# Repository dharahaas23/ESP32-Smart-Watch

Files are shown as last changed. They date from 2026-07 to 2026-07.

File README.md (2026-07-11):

# ESP32 Smart Watch

A round, wrist-worn smart watch built around the ESP32-WROOM-32, with heart-rate sensing, a circular color display, USB-C charging, and a custom PCB antenna — designed as part of the #30DaysOfPCB progression from beginner to advanced boards.

 

## Overview

| | |
|---|---|
| **MCU** | ESP32-WROOM-32 |
| **Display** | GC9A01, round TFT (SPI) |
| **Heart-rate sensor** | MAX30102 (I2C) |
| **Charger / protection** | TP4056 + DW01A + FS8205A dual MOSFET |
| **Regulator** | AMS1117-3.3 |
| **USB / programming** | USB-C, CH340K USB-to-TTL bridge |
| **Board shape** | Circular, with a keep-out zone and PCB trace antenna for the ESP32 |
| **Layers** | 4-layer (F.Cu, In1.Cu, In2.Cu, B.Cu) |
| **Pads / Vias / Track segments** | 227 / 78 / 306 |
| **Nets** | 68 (fully routed — 0 unrouted) |

## Features

- **ESP32-WROOM-32** as the main controller, with dedicated `RESET`, `EN`, `BOOT`, and `Button` GPIOs
- **GC9A01 round display** driven over SPI, with separate SDA/SCL/RST/DC/CS lines
- **MAX30102** heart-rate/SpO2 sensor on I2C, footprint placed close to the skin-contact edge for optimal readings
- **USB-C** input for power and CH340K-based UART programming (TXD/RXD/DTR/RTS wired to EN/BOOT for auto-reset)
- **TP4056** single-cell Li-ion charge management with **DW01A + FS8205A** battery protection (over-charge/discharge/current)
- **On/off slide switch** and separate **BOOT** and **Function** push buttons
- **Custom PCB trace antenna** for the ESP32, isolated behind a defined keep-out zone
- Battery connector (BAT+ / BAT−) for a coin/pouch cell

## Design Notes

- Front copper is heavily used for power distribution and the ESP32 antenna keep-out; back copper carries the bulk of signal routing.
- The board silkscreen calls out `PLACE CLOSE TO THE SKIN` next to the MAX30102 footprint as a placement reminder for future revisions/enclosure design.
- Bottom silk includes maker/GitHub branding (`GitHub:dharahaas23`) and a "Designed with KiCad" mark.

## Tools

- **KiCad 10.0.1** — schematic capture, PCB layout, and 3D visualization

## Author

**S. Dharahaas**
GitHub: [@dharahaas23](https://github.com/dharahaas23)

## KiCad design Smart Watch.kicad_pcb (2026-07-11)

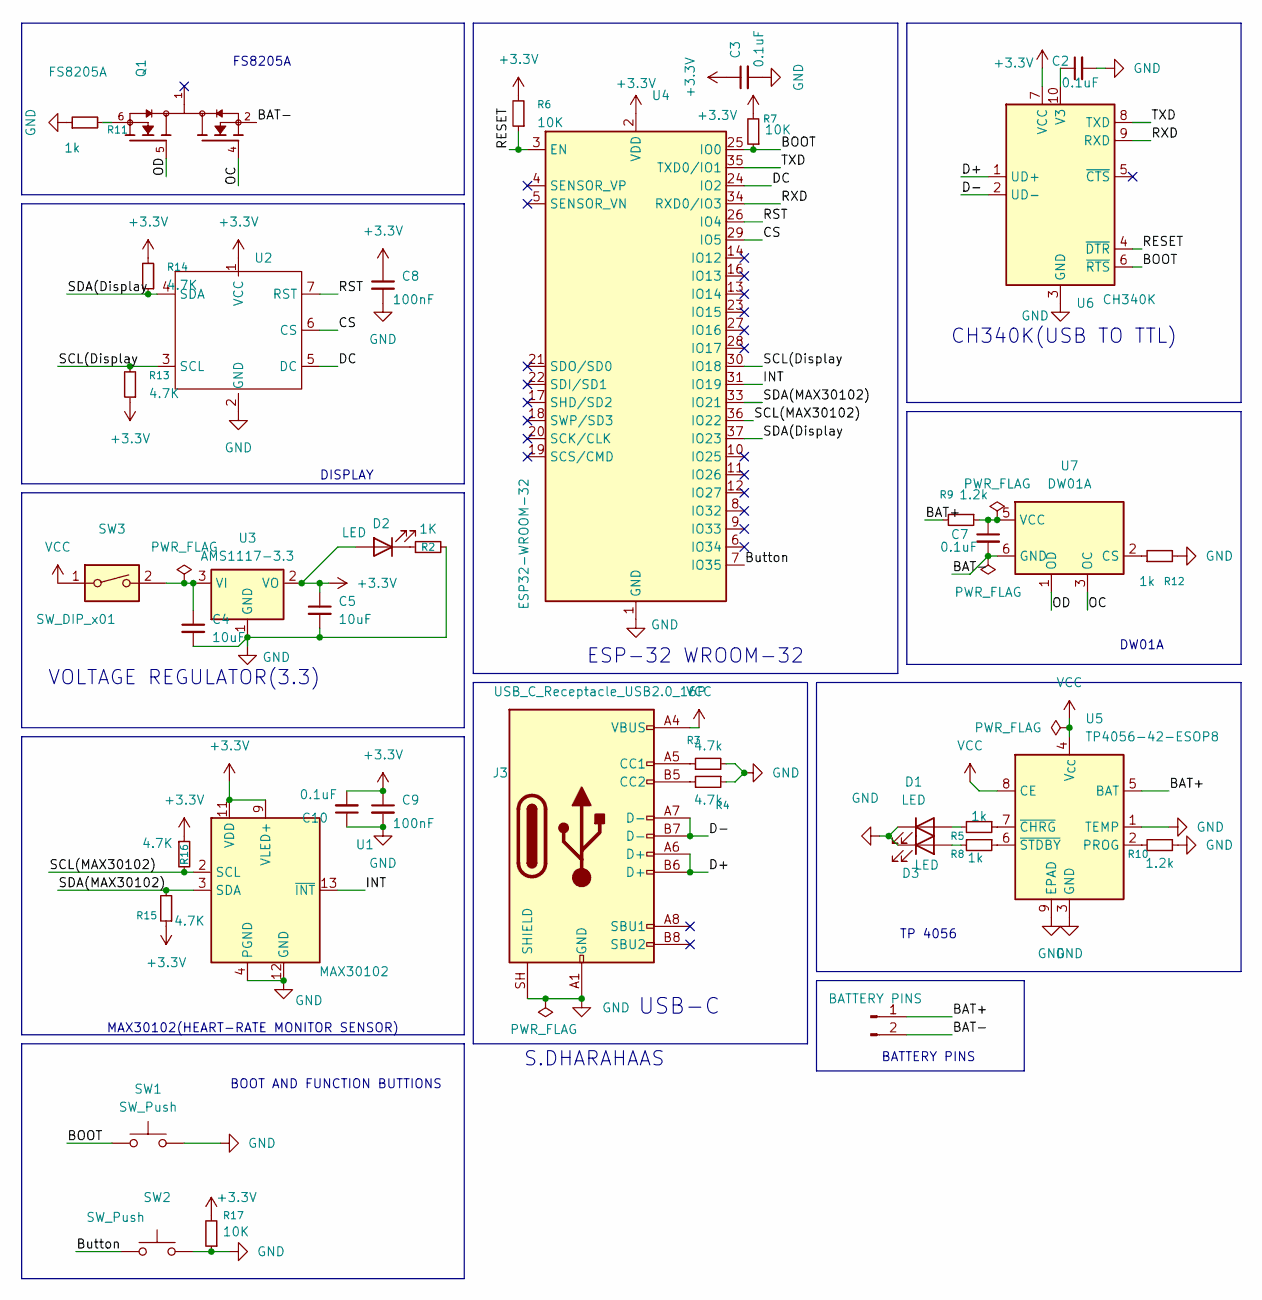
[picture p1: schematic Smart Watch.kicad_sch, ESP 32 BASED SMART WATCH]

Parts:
C2, C3, C7, C10: 0.1uF; C_0603_1608Metric
C4, C5: 10uF; C_0603_1608Metric
C8, C9: 100nF; C_0603_1608Metric
D1, D2, D3: LED; R_0805_2012Metric
J2: BATTERY PINS; JST_EH_S2B-EH_1x02_P2.50mm_Horizontal
J3: USB_C_Receptacle_USB2.0_16P; USB_C_Receptacle_HRO_TYPE-C-31-M-12
Q1: FS8205A; SOP65P640X120-8N; PARTREV 1.7
R2: 1K; R_0805_2012Metric
R3, R4: 4.7k; R_0805_2012Metric
R5, R8, R11, R12: 1k; R_0805_2012Metric
R6, R7, R17: 10K; R_0805_2012Metric
R9, R10: 1.2k; R_0805_2012Metric
R13, R14, R15, R16: 4.7K; R_0805_2012Metric
SW1, SW2: SW_Push; SW_SPST_TS-1088-xR025
SW3: SW_DIP_x01; SW_SPDT_PCM12
U1: MAX30102; Maxim_OLGA-14_3.3x5.6mm_P0.8mm
U2: Round display(mini)
U3: AMS1117-3.3; SOT-223-3_TabPin2
U4: ESP32-WROOM-32
U5: TP4056-42-ESOP8; SOIC-8-1EP_3.9x4.9mm_P1.27mm_EP2.41x3.3mm_ThermalVias
U6: CH340K; SSOP-10-1EP_3.9x4.9mm_P1mm_EP2.1x3.3mm
U7: DW01A; SOT-23-6

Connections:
+3.3V: C3.1, C5.1, C8.1, C9.1, C10.2, D2.2 (A), R6.2, R7.2, R13.1, R14.2, R15.1, R16.1, R17.2, U1.9 (VLED+), U1.10 (VLED+), U1.11 (VDD), U2.1 (VCC), U3.2 (VO), U4.2 (VDD), U6.7 (VCC)
/BAT+: J2.1, R9.2, U5.5 (BAT)
/BAT-: C7.2, J2.2, Q1.2, Q1.3, U7.6 (GND)
/BOOT: R7.1, SW1.1, U4.25 (IO0), U6.6 (~RTS)
/Button: SW2.1, U4.7 (IO35)
/CS: U2.6 (CS), U4.29 (IO5)
/D+: J3.A6 (D+), J3.B6 (D+), U6.1 (UD+)
/D-: J3.A7 (D-), J3.B7 (D-), U6.2 (UD-)
/DC: U2.5 (DC), U4.24 (IO2)
/INT: U1.13 (~INT), U4.31 (IO19)
/OC: Q1.4, U7.3 (OC)
/OD: Q1.5, U7.1 (OD)
/RESET: R6.1, U4.3 (EN), U6.4 (~DTR)
/RST: U2.7 (RST), U4.26 (IO4)
/RXD: U4.34 (RXD0/IO3), U6.9 (RXD)
/SCL(Display: R13.2, U2.3 (SCL), U4.30 (IO18)
/SCL(MAX30102): R16.2, U1.2 (SCL), U4.36 (IO22)
/SDA(Display: R14.1, U2.4 (SDA), U4.37 (IO23)
/SDA(MAX30102): R15.2, U1.3 (SDA), U4.33 (IO21)
/TXD: U4.35 (TXD0/IO1), U6.8 (TXD)
GND: C2.2, C3.2, C4.2, C5.2, C8.2, C9.2, C10.1, D1.1 (K), D3.1 (K), J3.A1 (GND), J3.A12 (GND), J3.B1 (GND), J3.B12 (GND), J3.SH (SHIELD), R2.2, R3.2, R4.1, R10.1, R11.1, R12.2, R17.1, SW1.2, SW2.2, U1.4 (PGND), U1.12 (GND), U2.2 (GND), U3.1 (GND), U4.1 (GND), U4.15 (GND), U4.38 (GND), U4.39 (GND), U5.1 (TEMP), U5.3 (GND), U5.9 (EPAD), U6.3 (GND), U6.11 (GND)
unnamed: D1.2 (A), R5.2
unnamed: D2.1 (K), R2.1
unnamed: D3.2 (A), R8.2
unnamed: J3.A5 (CC1), R3.1
unnamed: J3.B5 (CC2), R4.2
unnamed: Q1.6, Q1.7, R11.2
unnamed: C4.1, SW3.2, U3.3 (VI)
unnamed: R10.2, U5.2 (PROG)
unnamed: R5.1, U5.7 (~CHRG)
unnamed: R8.1, U5.6 (~STDBY)
unnamed: C2.1, U6.10 (V3)
unnamed: R12.1, U7.2 (CS)
unnamed: C7.1, R9.1, U7.5 (VCC)
VCC: J3.A4 (VBUS), J3.A9 (VBUS), J3.B4 (VBUS), J3.B9 (VBUS), SW3.1, U5.4 (V_{CC}), U5.8 (CE)

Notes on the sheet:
DW01A
FS8205A
MAX30102(HEART-RATE MONITOR SENSOR)
S.DHARAHAAS
CH340K(USB TO TTL)
BOOT AND FUNCTION BUTTIONS
TP 4056
BATTERY PINS
ESP-32 WROOM-32
DISPLAY
VOLTAGE REGULATOR(3.3)
USB-C

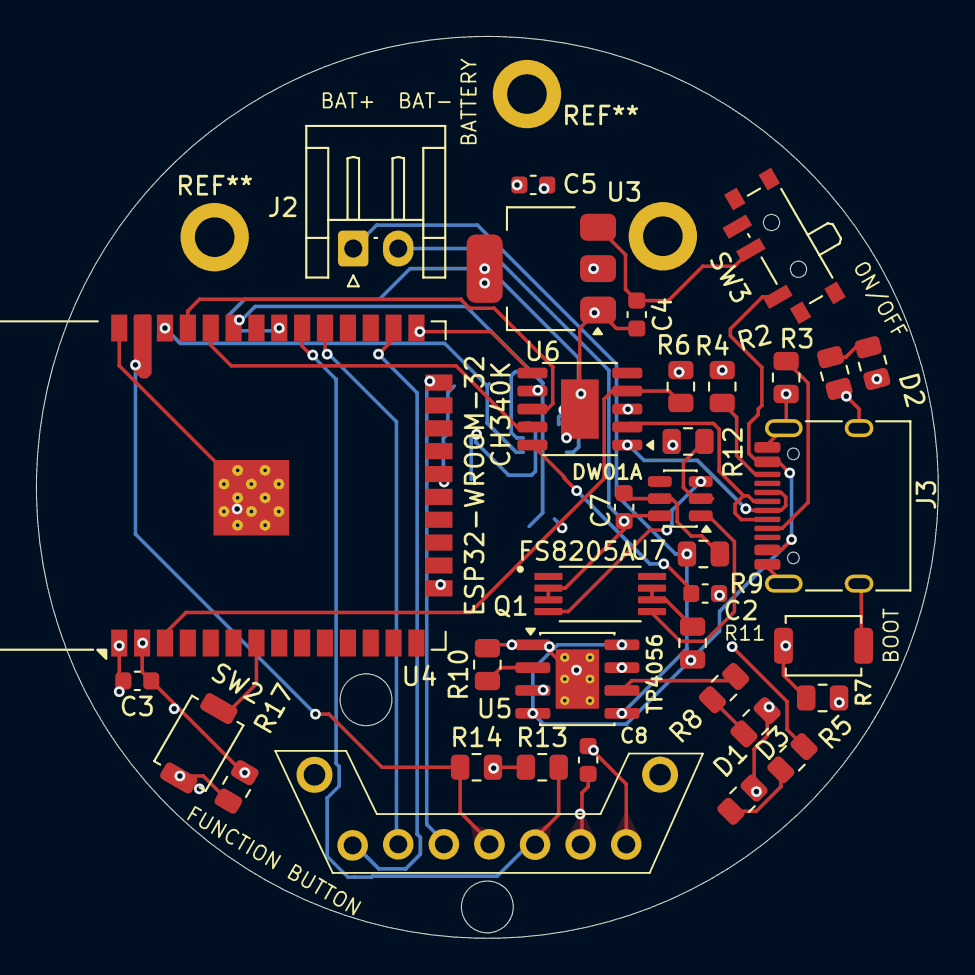
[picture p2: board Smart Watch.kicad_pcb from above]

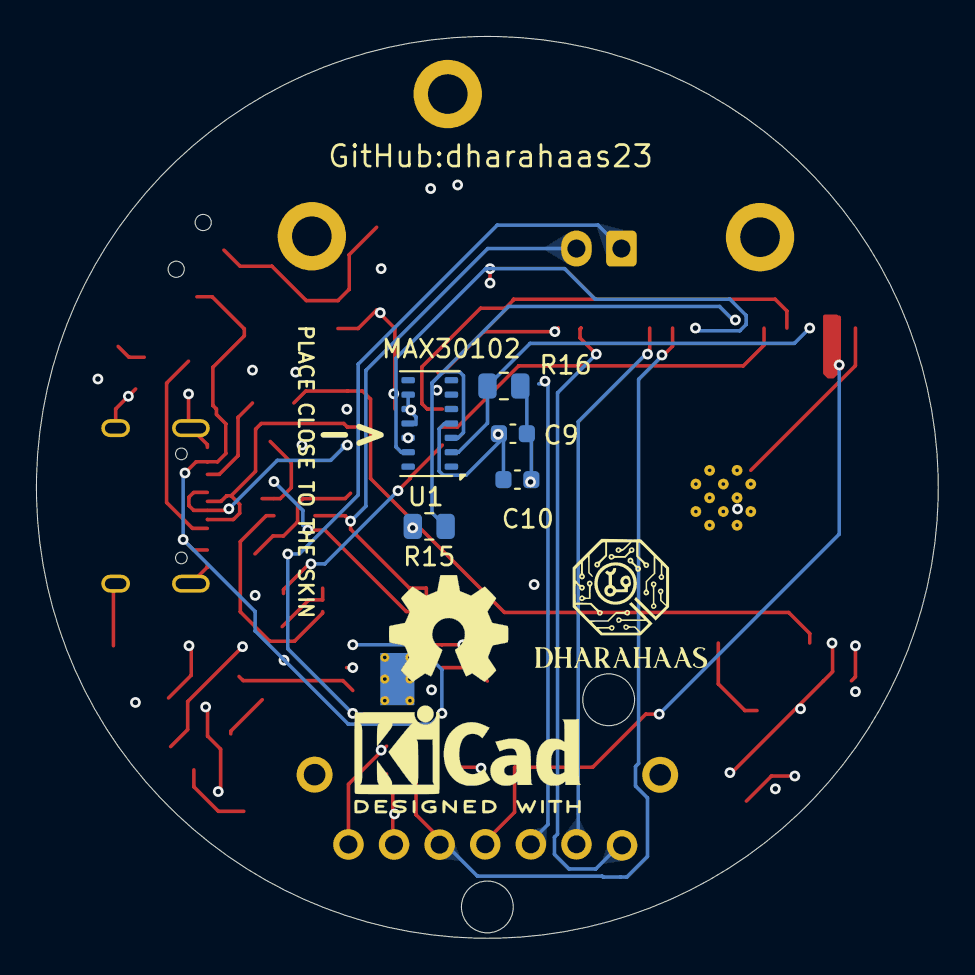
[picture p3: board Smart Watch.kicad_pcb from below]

Board: 4 copper layers, 50.1 x 50.1 mm, 40 parts (5 on the bottom side), 35 nets.
